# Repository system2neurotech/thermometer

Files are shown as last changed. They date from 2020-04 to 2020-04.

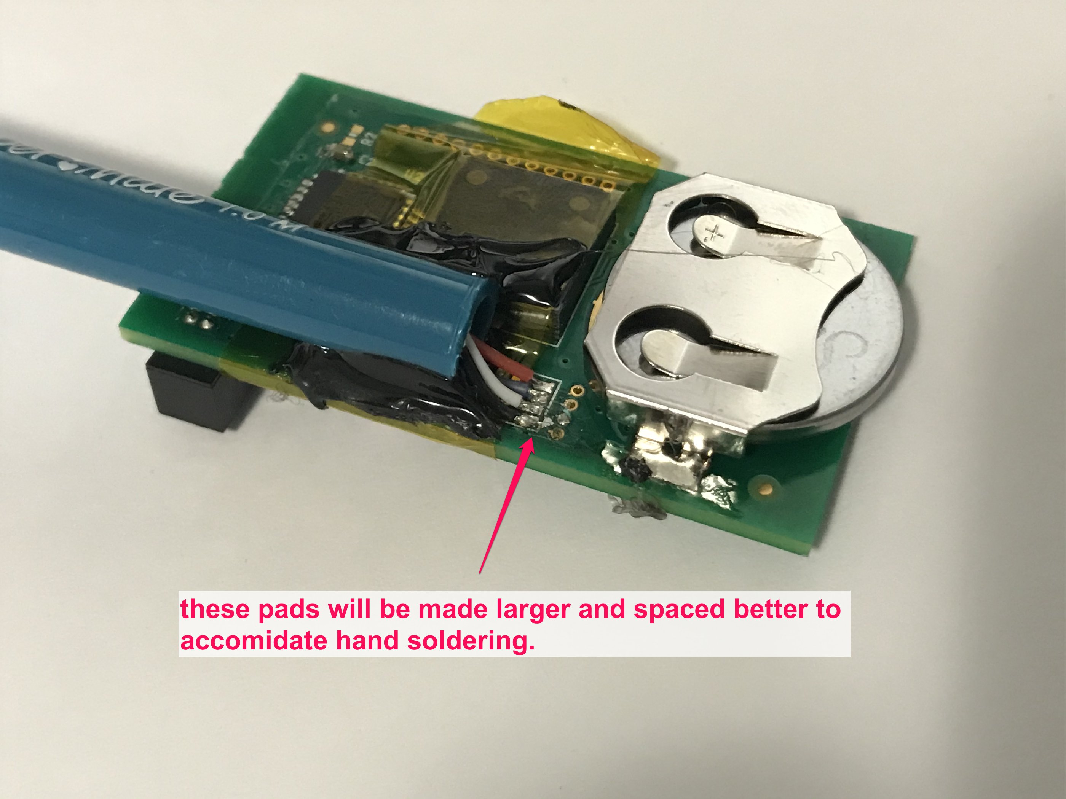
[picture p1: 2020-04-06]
assembly pictures/main_board_wiring_033120_010513_PM.jpg

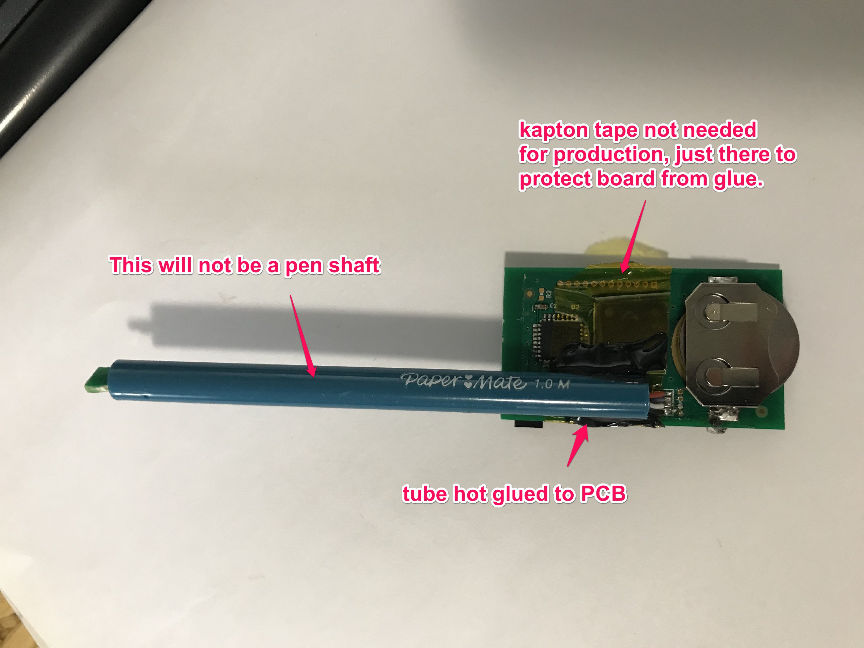
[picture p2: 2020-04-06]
assembly pictures/back_side_033120_010354_PM.jpg

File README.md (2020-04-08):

# thermometer
Easy to make thermometer using available parts that don't require calibration. 

Building the Firmware 

Use STM32CubeIDE (https://www.st.com/en/development-tools/stm32cubeide.html)

For LCD use the  LCD brance, for LED use the LED branch. You can construct the hardware with either LCD support or LED support, but not both!

The PCB design has been modified since the incarnation I used for testing. Please check it before manufacturing it.

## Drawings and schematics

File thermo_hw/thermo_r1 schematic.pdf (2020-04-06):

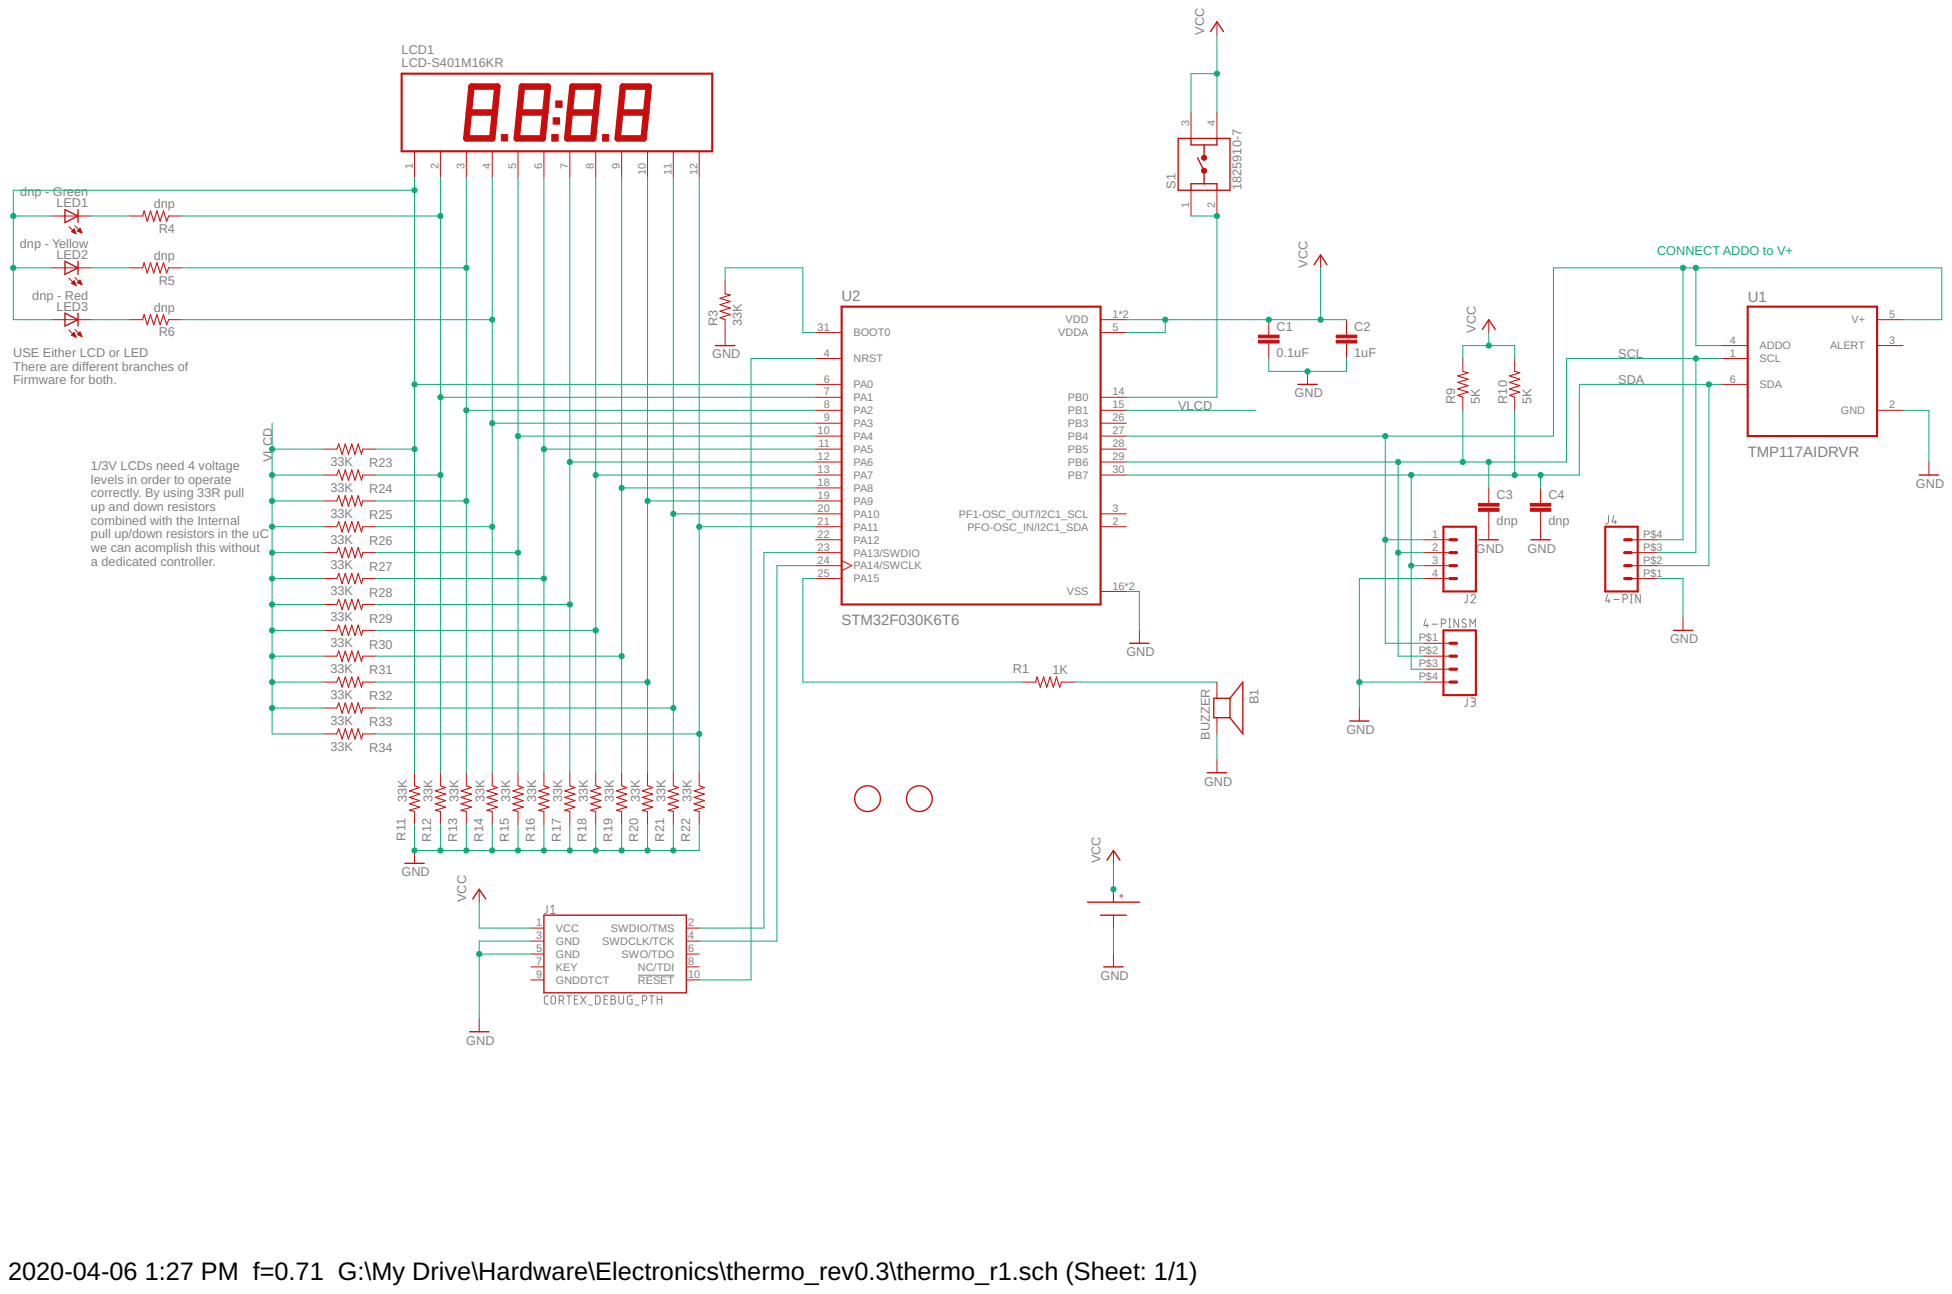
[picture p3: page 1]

USE Either LCD or LED
There are different branches of Firmware for both. 1/3V LCDs need 4 voltage

levels in order to operate
correctly. By using 33R pull up and down resistors

combined with the Internal pull up/down resistors in the uC

we can acomplish this without a dedicated controller.

2020-04-06 1:27 PM f=0.71 G:\My Drive\Hardware\Electronics\thermo_rev0.3\thermo_r1.sch (Sheet: 1/1)

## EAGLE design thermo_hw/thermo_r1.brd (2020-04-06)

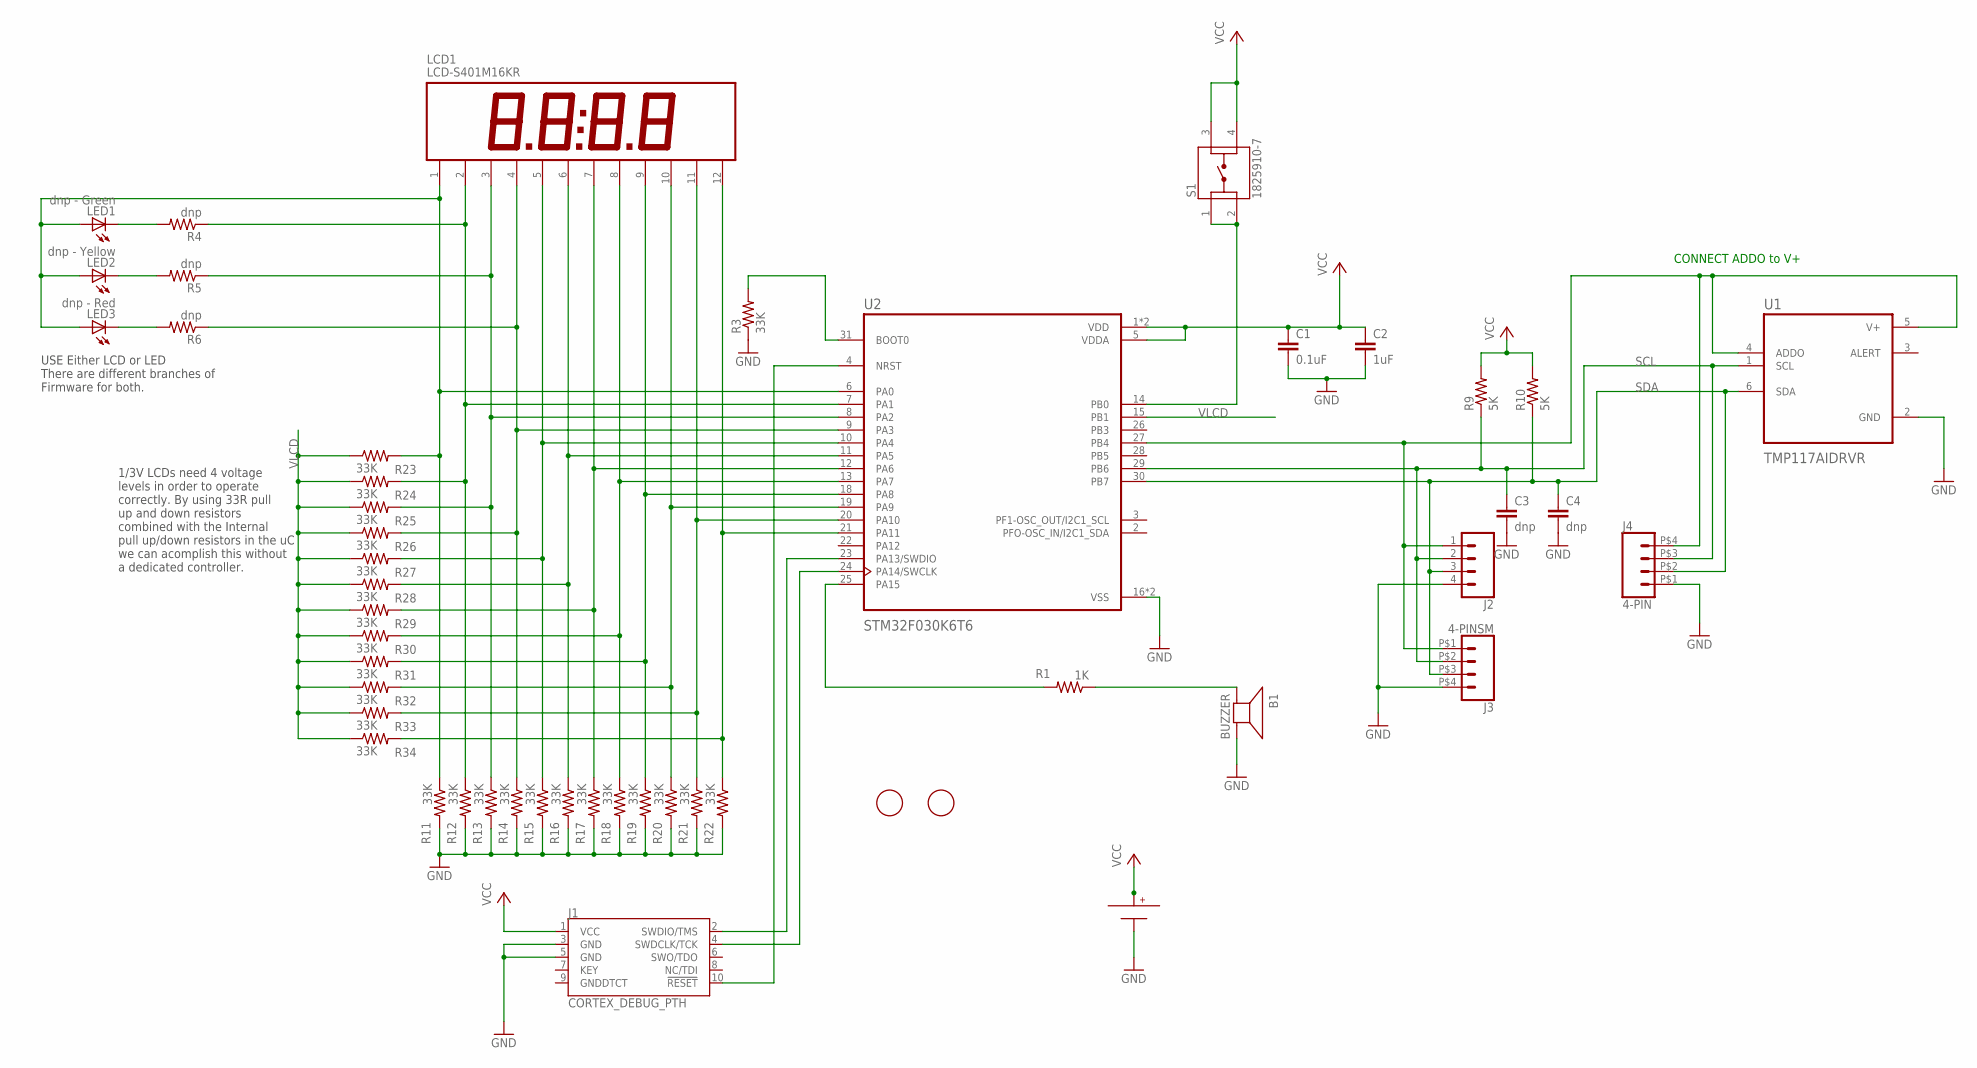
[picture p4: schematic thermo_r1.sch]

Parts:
B1: BUZZER; PLKCS1212E
BT1: BAT-HLD-001
C1: 0.1uF; R0603
C2: 1uF; R0603
C3, C4: dnp; R0603
J1: CORTEX_DEBUG_PTH; 2X5-PTH-1.27MM
J2: CONN_041.27MM; 1X04_1.27MM
J3: 4-PINSM; 4PIN_1MM
J4: 4-PIN; 2X2PIN_1MM
LCD1: LCD-S401M16KR
LED1: dnp - Green; CHIP-LED0805
LED2: dnp - Yellow; CHIP-LED0805
LED3: dnp - Red; CHIP-LED0805
R1: 1K; R0603
R3, R11, R12, R13, R14, R15, R16, R17, R18, R19, R20, R21, R22, R23, R24, R25, R26, R27, R28, R29, R30, R31, R32, R33, R34: 33K; R0603
R4, R5, R6: dnp; R0603
R9, R10: 5K; R0603
S1: 1825910-7; SW_1825910-7
U1: TMP117AIDRVR; SON65P200X200X80-7N
U2: STM32F030K6T6; QFP80P900X900X160-32N
U$5, U$6: FIDUCIAL; FIDUCIAL_1MM

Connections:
GND: B1.P$2 (-), BT1.-, C1.2, C2.2, C3.2, C4.2, J1.3 (GND), J1.5 (GND), J2.4, J3.P$4 (4), J4.P$1 (1), R3.1, R11.2, R12.2, R13.2, R14.2, R15.2, R16.2, R17.2, R18.2, R19.2, R20.2, R21.2, R22.2, U1.2 (GND), U2.16 (VSS), U2.32 (VSS)
unnamed: J1.4 (SWDCLK/TCK), U2.24 (PA14/SWCLK)
unnamed: LCD1.2, R4.1, R12.1, R24.2, U2.7 (PA1)
unnamed: LCD1.3, R5.1, R13.1, R25.2, U2.8 (PA2)
unnamed: LCD1.4, R6.1, R14.1, R26.2, U2.9 (PA3)
unnamed: LCD1.5, R15.1, R27.2, U2.10 (PA4)
unnamed: LCD1.6, R16.1, R28.2, U2.11 (PA5)
unnamed: LCD1.7, R17.1, R29.2, U2.12 (PA6)
unnamed: LCD1.8, R18.1, R30.2, U2.13 (PA7)
unnamed: LCD1.9, R19.1, R31.2, U2.18 (PA8)
unnamed: LCD1.10, R20.1, R32.2, U2.19 (PA9)
unnamed: LCD1.11, R21.1, R33.2, U2.20 (PA10)
unnamed: LCD1.12, R22.1, R34.2, U2.21 (PA11)
unnamed: R1.2, U2.25 (PA15)
unnamed: R3.2, U2.31 (BOOT0)
unnamed: J1.10 (!RESET), U2.4 (NRST)
unnamed: J1.2 (SWDIO/TMS), U2.23 (PA13/SWDIO)
unnamed: B1.P$1 (+), R1.1
unnamed: LED3.C, R6.2
unnamed: S1.1, S1.2, U2.14 (PB0)
unnamed: LED2.C, R5.2
unnamed: LED1.C, R4.2
unnamed: LCD1.1, LED1.A, LED2.A, LED3.A, R11.1, R23.2, U2.6 (PA0)
SCL: C3.1, J2.2, J3.P$2 (2), J4.P$3 (3), R9.1, U1.1 (SCL), U2.29 (PB6)
SDA: C4.1, J2.3, J3.P$3 (3), J4.P$2 (2), R10.1, U1.6 (SDA), U2.30 (PB7)
VCC: BT1.+@1 (+), BT1.+@2 (+), C1.1, C2.1, J1.1 (VCC), R9.2, R10.2, S1.3, S1.4, U2.1 (VDD), U2.5 (VDDA), U2.17 (VDD)
VLCD: R23.1, R24.1, R25.1, R26.1, R27.1, R28.1, R29.1, R30.1, R31.1, R32.1, R33.1, R34.1, U2.15 (PB1)
VT: J2.1, J3.P$1 (1), J4.P$4 (4), U1.4 (ADDO), U1.5 (V+), U2.27 (PB4)

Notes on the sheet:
CONNECT ADDO to V+
USE Either LCD or LED There are different branches of Firmware for both.
1/3V LCDs need 4 voltage levels in order to operate correctly. By using 33R pull up and down resistors combined with the Internal pull up/down resistors in the uC we can acomplish this without a dedicated controller.

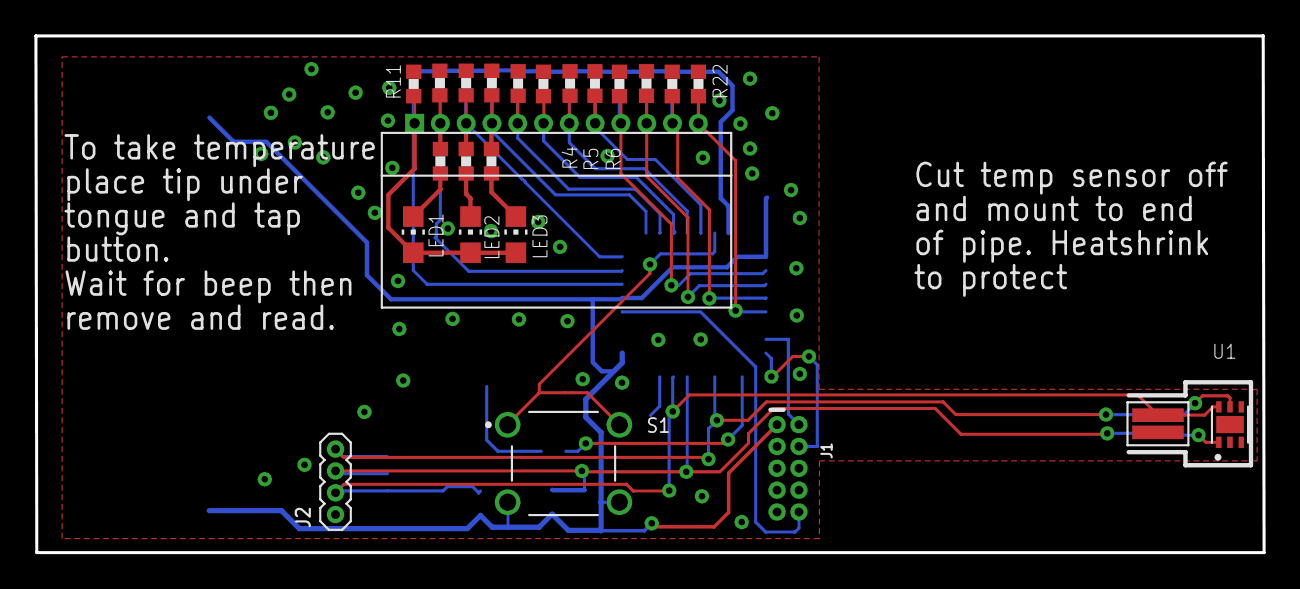
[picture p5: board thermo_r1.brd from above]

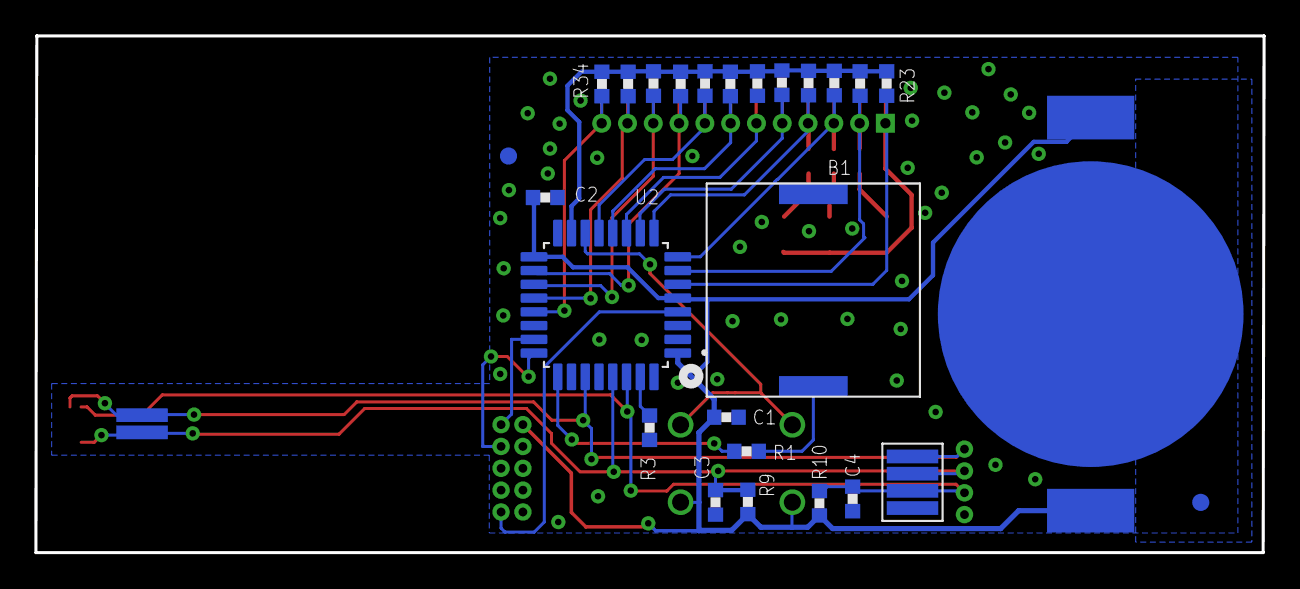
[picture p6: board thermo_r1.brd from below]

Board: 2 copper layers, 71.4 x 30.0 mm, 50 parts (26 on the bottom side), 28 nets.

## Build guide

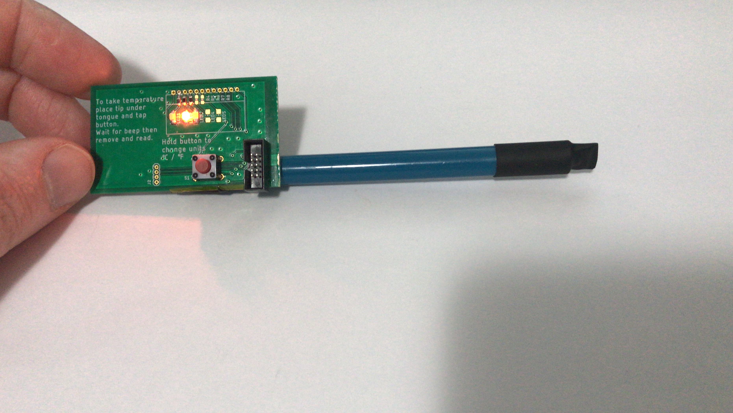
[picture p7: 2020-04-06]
assembly pictures/28C83EF2-D8EF-4983-AB79-15C459B0D78E.JPG

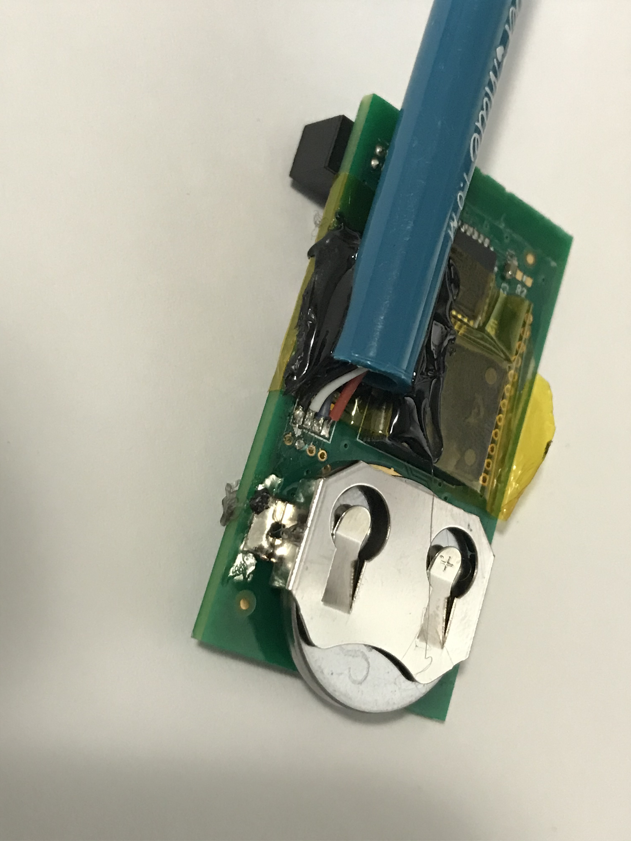
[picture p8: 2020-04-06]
assembly pictures/main board wiring.jpg

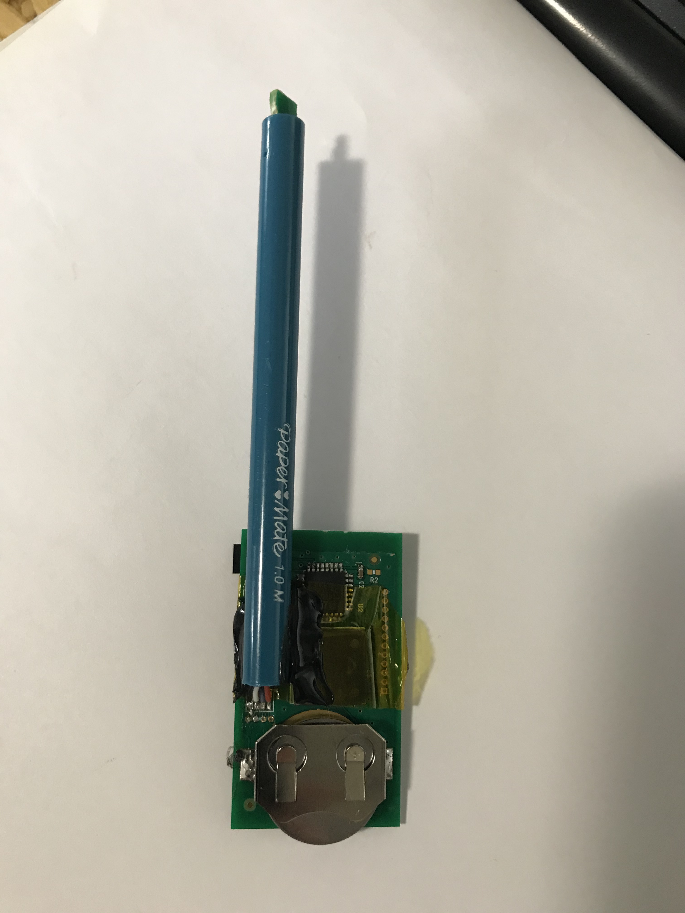
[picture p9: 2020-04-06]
assembly pictures/back side.jpg

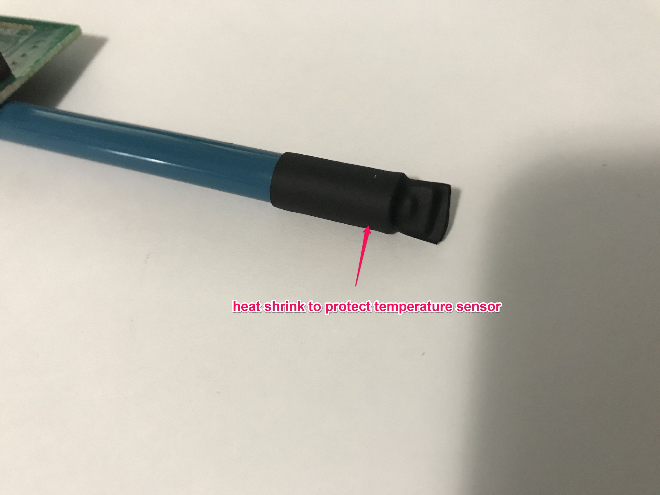
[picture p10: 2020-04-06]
assembly pictures/heat_shrink_033120_010430_PM.jpg

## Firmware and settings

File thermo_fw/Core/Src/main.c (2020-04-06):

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

/* Includes ------------------------------------------------------------------*/
#include "main.h"

/* USER CODE BEGIN Includes */
#include "thermo.h"
#include "tmp117.h"

/* USER CODE END Includes */

/* USER CODE BEGIN PD */
#define SLEEP_TIMEOUT 90000  // 15 second sleep timeout
/* USER CODE END PD */

I2C_HandleTypeDef hi2c1;

TIM_HandleTypeDef htim2;
TIM_HandleTypeDef htim16;
TIM_HandleTypeDef htim17;

void SystemClock_Config(void);
static void MX_GPIO_Init(void);
static void MX_GPIO_DeInit(void);
static void MX_I2C1_Init(void);
static void MX_TIM2_Init(void);
static void MX_TIM16_Init(void);
static void MX_TIM17_Init(void);
/**
  * @brief  The application entry point.
  * @retval int
  */
int main(void)
{
  

  /* MCU Configuration--------------------------------------------------------*/

  /* Reset of all peripherals, Initializes the Flash interface and the Systick. */
  HAL_Init();

  /* Configure the system clock */
  SystemClock_Config();

  /* Initialize all configured peripherals */
  MX_GPIO_Init();
  MX_I2C1_Init();
  MX_TIM2_Init();
  MX_TIM16_Init();
  MX_TIM17_Init();
  /* USER CODE BEGIN 2 */
  //tmp_init();

  uint32_t wakeup_time = HAL_GetTick() - SLEEP_TIMEOUT;

  /* USER CODE END 2 */

  /* Infinite loop */
  /* USER CODE BEGIN WHILE */
  while (1)
  {
    /* USER CODE END WHILE */

    /* USER CODE BEGIN 3 */
	  // loop until it's time to go to sleep.
	  while((wakeup_time + SLEEP_TIMEOUT) > HAL_GetTick()){
		  if((HAL_GPIO_ReadPin(BUTTON_GPIO_Port, BUTTON_Pin)) &&
			 (get_thermo_status()	== THERMO_DONE))
		  {
			  reset_temp_measurements();
			  HAL_TIM_Base_Start_IT(&htim17);
			  HAL_TIM_Base_Start_IT(&htim16);
			  wakeup_time = HAL_GetTick();
			  set_thermo_status(THERMO_READING);
		  }
	  }

	  // turn off the power to the temp sensor
		HAL_TIM_PWM_Stop(&htim2, TIM_CHANNEL_2) ;
		HAL_TIM_PWM_Stop(&htim2, TIM_CHANNEL_3) ;
		HAL_TIM_PWM_Stop(&htim2, TIM_CHANNEL_4) ;

		HAL_TIM_Base_Stop(&htim16);
		HAL_TIM_Base_Stop(&htim17);
	  tmp_powerdown();
	  // if in debug mode, we just loop and wait for the button press
	  //while(HAL_GPIO_ReadPin(BUTTON_GPIO_Port, BUTTON_Pin));
	  HAL_GPIO_WritePin(GPIOA, GPIO_PIN_0, GPIO_PIN_RESET);
	  __disable_irq();
	  //HAL_TIM_MspPostDeInit(&htim2);
	  //HAL_TIM_Base_MspDeInit(&htim2);
	  //HAL_TIM_Base_MspDeInit(&htim16);
	  //HAL_TIM_Base_MspDeInit(&htim17);
	  //HAL_I2C_MspDeInit(&hi2c1);
	  MX_GPIO_DeInit();
	  HAL_PWR_EnterSTOPMode(PWR_LOWPOWERREGULATOR_ON, PWR_STOPENTRY_WFE);
	  //while(!HAL_GPIO_ReadPin(BUTTON_GPIO_Port, BUTTON_Pin));
	  MX_GPIO_Init();
	  //HAL_PWR_EnterSTANDBYMode();
	  HAL_TIM_MspPostInit(&htim2);
	  //HAL_TIM_Base_MspInit(&htim2);
	  //HAL_TIM_Base_MspInit(&htim16);
	  //HAL_TIM_Base_MspInit(&htim17);
	  HAL_I2C_MspInit(&hi2c1);
	  HAL_GPIO_WritePin(GPIOA, GPIO_PIN_0, GPIO_PIN_SET);
	  __enable_irq();
	  // when you wakeup, turn on the temp sensor, reset the LCD value and start the timers

	  tmp_powerup();
	  reset_temp_measurements();
	  HAL_TIM_Base_Start_IT(&htim16);
	  HAL_TIM_Base_Start_IT(&htim17);
	  set_thermo_status(THERMO_READING);

	  wakeup_time = HAL_GetTick();

  }
  /* USER CODE END 3 */
}

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
/* USER CODE BEGIN 4 */
void LED_toggle(void){
	static int led_state = 0;
	if(led_state == 0)
	{
		HAL_TIM_PWM_Start(&htim2, TIM_CHANNEL_2) ;
		HAL_TIM_PWM_Stop(&htim2, TIM_CHANNEL_4) ;
		led_state = 1;
	}
	else if(led_state == 1)
	{
		HAL_TIM_PWM_Start(&htim2, TIM_CHANNEL_4) ;
		HAL_TIM_PWM_Stop(&htim2, TIM_CHANNEL_2) ;
		led_state = 0;
	}

}


void HAL_TIM_PeriodElapsedCallback(TIM_HandleTypeDef *htim)
{
	//if(htim->Instance == TIM16)
		LED_toggle();
	if(htim->Instance == TIM17)
		read_temp();
}
/* USER CODE END 4 */
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


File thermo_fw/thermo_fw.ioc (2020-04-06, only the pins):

Mcu.UserName=STM32F031K6Tx
PA0.Signal=GPIO_Output
PA1.GPIO_Label=LED_GREEN
PA1.Signal=S_TIM2_CH2
PA13.GPIO_Label=SWDIO
PA13.Signal=SYS_SWDIO
PA14.GPIO_Label=SWCLK
PA14.Signal=SYS_SWCLK
PA15.GPIO_Label=BUZZ
PA15.Signal=S_TIM2_CH1_ETR
PA2.GPIO_Label=LED_ORANGE
PA2.Signal=S_TIM2_CH3
PA3.GPIO_Label=LED_RED
PA3.Signal=S_TIM2_CH4
PB0.GPIO_Label=BUTTON
PB0.Signal=GPXTI0
PB3.Signal=GPIO_Input
PB4.GPIO_Label=VTEMP
PB4.Signal=GPIO_Output
PB6.Signal=I2C1_SCL
PB7.Signal=I2C1_SDA

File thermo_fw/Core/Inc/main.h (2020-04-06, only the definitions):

#define LED_GREEN_Pin GPIO_PIN_1
#define LED_GREEN_GPIO_Port GPIOA
#define LED_ORANGE_Pin GPIO_PIN_2
#define LED_ORANGE_GPIO_Port GPIOA
#define LED_RED_Pin GPIO_PIN_3
#define LED_RED_GPIO_Port GPIOA
#define BUTTON_Pin GPIO_PIN_0
#define BUTTON_GPIO_Port GPIOB
#define SWDIO_Pin GPIO_PIN_13
#define SWDIO_GPIO_Port GPIOA
#define SWCLK_Pin GPIO_PIN_14
#define SWCLK_GPIO_Port GPIOA
#define BUZZ_Pin GPIO_PIN_15
#define BUZZ_GPIO_Port GPIOA
#define VTEMP_Pin GPIO_PIN_4
#define VTEMP_GPIO_Port GPIOB

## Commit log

2020-04-06 Adding files.
    [thermo_r1.brd, thermo_r1.sch]
2020-04-06 added assembly pictures

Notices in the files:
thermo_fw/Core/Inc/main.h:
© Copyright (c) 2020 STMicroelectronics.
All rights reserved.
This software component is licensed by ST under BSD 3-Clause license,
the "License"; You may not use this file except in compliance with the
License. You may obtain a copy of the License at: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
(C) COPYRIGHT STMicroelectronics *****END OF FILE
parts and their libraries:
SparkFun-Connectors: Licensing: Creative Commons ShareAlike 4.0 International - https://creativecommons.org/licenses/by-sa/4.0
